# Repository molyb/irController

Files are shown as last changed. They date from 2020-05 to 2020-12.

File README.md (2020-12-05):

# irController

[PCB board](pcb) and [firmware](firmware)

# Mode Select
## Normal Mode
This mode can control consumer electronics.  

1. Just turn on or release the reset button.
2. Access the ip address that allocated by your router. 

## Network Config Mode
This mode configure Wi-Fi.
   
1. Press program button within one second of releasing the reset button,
    and hold down it for one second.
2. Connect to IR_CONTROLLER_AP.
3. You will be redirected to the configuration page automatically.
4. Input ssid and password, and click save button.

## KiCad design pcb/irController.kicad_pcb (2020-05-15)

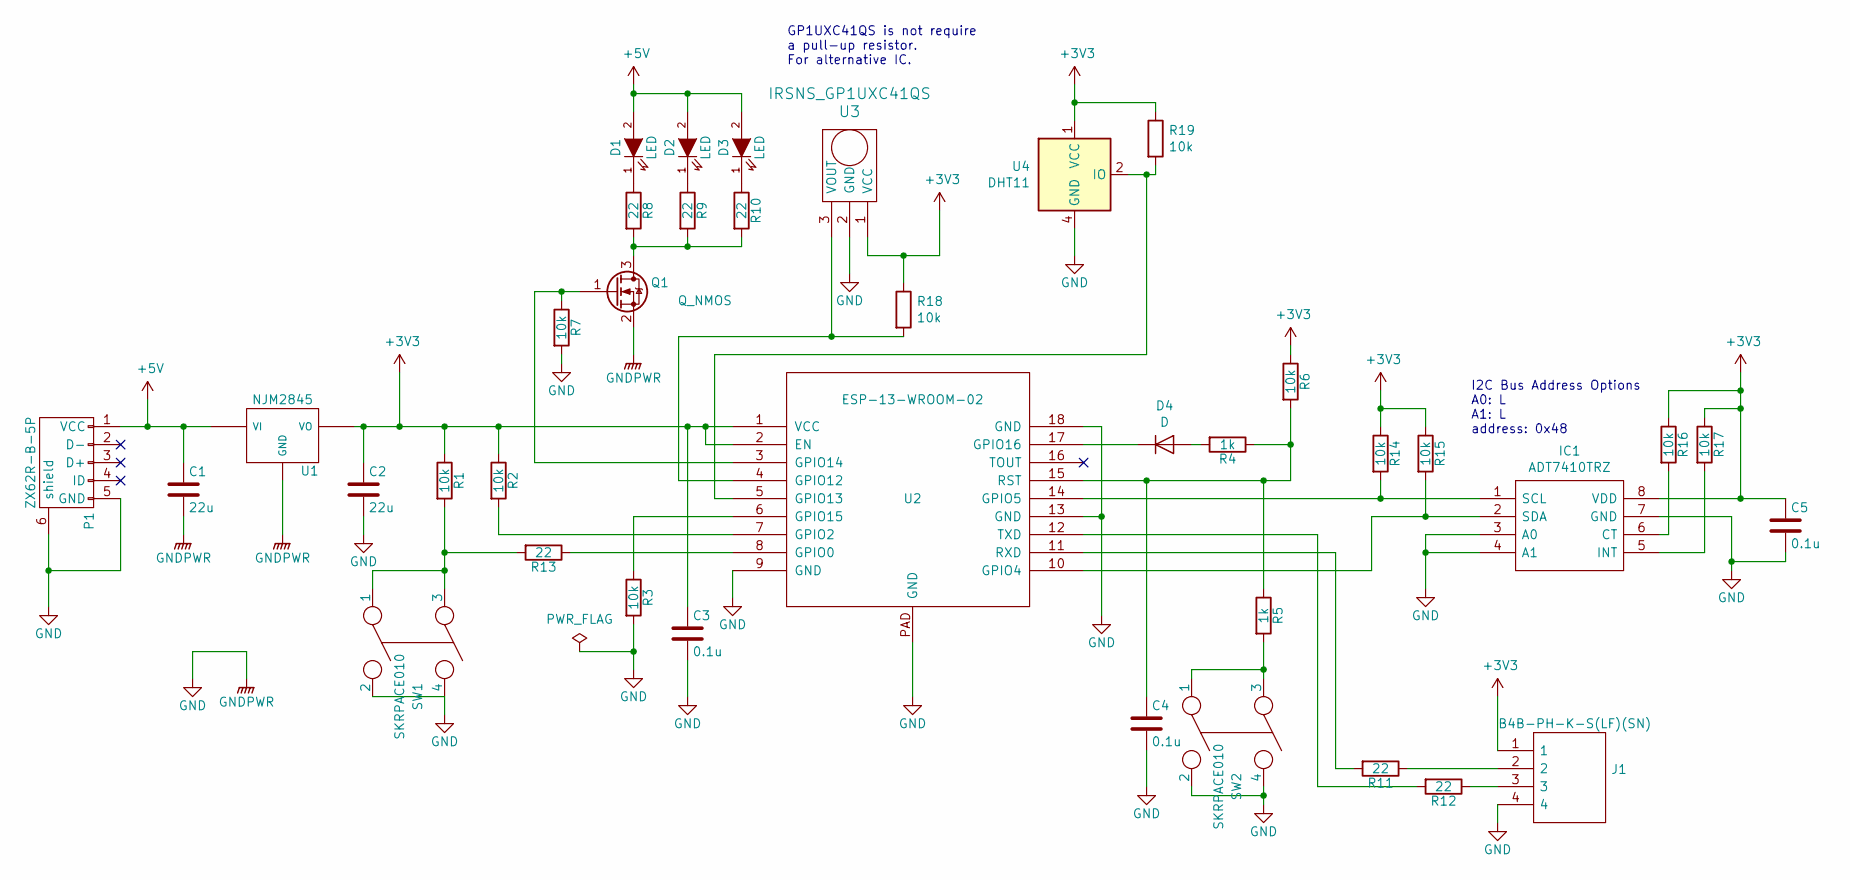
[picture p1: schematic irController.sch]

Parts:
C1, C2: 22u; C_1206_3216Metric
C3, C4, C5: 0.1u; C_0603_1608Metric
D1, D2, D3: LED; LED-5MM
D4: D; D_SOD-123F
IC1: ADT7410TRZ; SOIC127P600X175-8N; Manufacturer_Part_Number ADT7410TRZ; Mouser Part Number 584-ADT7410TRZ
J1: B4B-PH-K-S(LF)(SN); SHDR4W60P0X200_1X4_990X450X600P; Manufacturer_Part_Number B4B-PH-K-S(LF)(SN)
P1: ZX62R-B-5P; USB_Micro-B_Wuerth_629105150521
Q1: Q_NMOS; SOT-23
R1, R2, R3, R6, R7, R14, R15, R16, R17, R18, R19: 10k; R_0603_1608Metric
R4, R5: 1k; R_0603_1608Metric
R8, R9, R10, R11, R12, R13: 22; R_0603_1608Metric
SW1, SW2: SKRPACE010
U1: NJM2845; TO-252-3
U2: ESP-13-WROOM-02
U3: IRSNS_GP1UXC41QS; Socket_Strip_Straight_1x03
U4: DHT11; PinHeader_1x04_P2.54mm_Vertical

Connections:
+3V3: C2.1, C3.1, C5.1, IC1.8 (VDD), J1.1, R1.1, R2.1, R6.1, R14.1, R15.1, R16.1, R17.1, R18.1, R19.1, U1.VO, U2.1 (VCC), U2.2 (EN), U3.1 (VCC), U4.1 (VCC)
+5V: C1.1, D1.2 (A), D2.2 (A), D3.2 (A), P1.1 (VCC), U1.VI
GND: C1.2, C2.2, C3.2, C4.2, C5.2, IC1.3 (A0), IC1.4 (A1), IC1.7 (GND), J1.4, P1.5 (GND), P1.6 (shield), Q1.2 (S), R3.2, R7.2, SW1.2, SW1.4, SW2.2, SW2.4, U1.GND, U2.9 (GND), U2.13 (GND), U2.18 (GND), U2.PAD (GND), U3.2 (GND), U4.4 (GND)
unnamed: C4.1, R4.1, R5.1, R6.2, U2.15 (RST)
unnamed: D1.1 (K), R8.1
unnamed: D2.1 (K), R9.1
unnamed: D3.1 (K), R10.1
unnamed: D4.1 (K), U2.17 (GPIO16)
unnamed: D4.2 (A), R4.2
unnamed: IC1.1 (SCL), R14.2, U2.14 (GPIO5)
unnamed: IC1.2 (SDA), R15.2, U2.10 (GPIO4)
unnamed: IC1.5 (INT), R17.2
unnamed: IC1.6 (CT), R16.2
unnamed: J1.2, R11.1
unnamed: J1.3, R12.1
unnamed: Q1.1 (G), R7.1, U2.3 (GPIO14)
unnamed: Q1.3 (D), R8.2, R9.2, R10.2
unnamed: R1.2, R13.2, SW1.1, SW1.3
unnamed: R2.2, U2.7 (GPIO2)
unnamed: R3.1, U2.6 (GPIO15)
unnamed: R5.2, SW2.1, SW2.3
unnamed: R11.2, U2.11 (RXD)
unnamed: R12.2, U2.12 (TXD)
unnamed: R13.1, U2.8 (GPIO0)
unnamed: R18.2, U2.4 (GPIO12), U3.3 (VOUT)
unnamed: R19.2, U2.5 (GPIO13), U4.2 (IO)

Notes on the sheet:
I2C Bus Address Options A0: L A1: L address: 0x48
GP1UXC41QS is not require a pull-up resistor. For alternative IC.

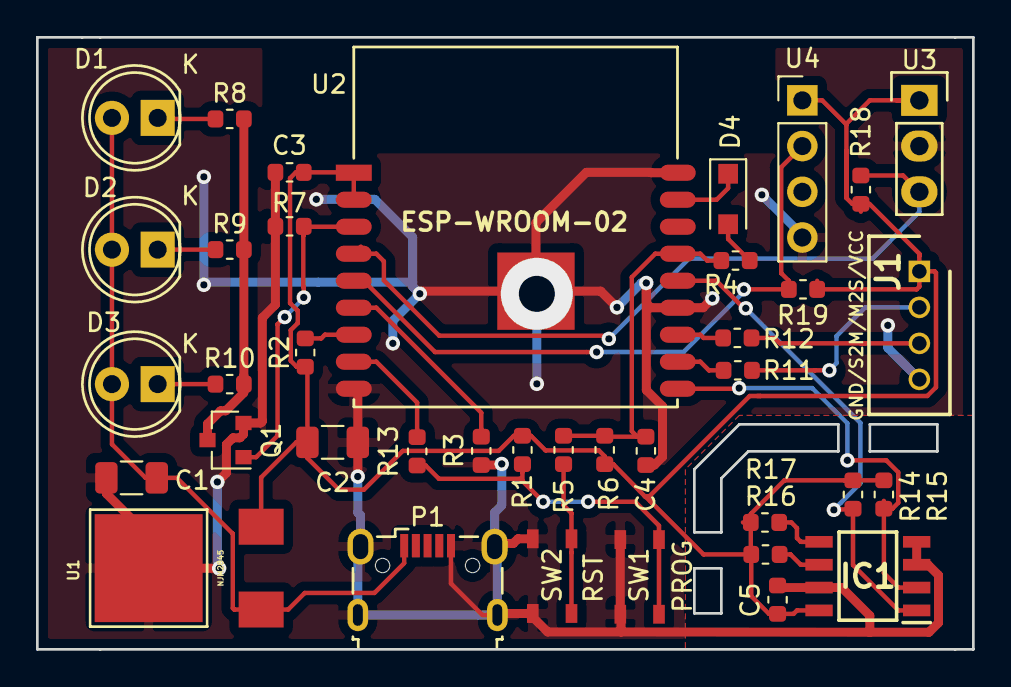
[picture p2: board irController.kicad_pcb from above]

Board: 2 copper layers, 52.0 x 34.0 mm, 38 parts (0 on the bottom side), 26 nets.

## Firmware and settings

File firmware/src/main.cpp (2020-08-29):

#include <Arduino.h>

#include "configMode.h"
#include "operationMode.h"

#define PROG_BUTTON 0


enum Mode {
    kOperationMode, kConfigMode
};

enum Mode mode = kOperationMode;

void setup() {
    pinMode(PROG_BUTTON, INPUT);
    // リセット解除後 1secの時点でボタンが押下されていればWifiの設定モードに入る
    delay(1000);
    if (digitalRead(PROG_BUTTON) == LOW) {
        mode = kConfigMode;
        setupConfigMode();
    } else {
        setupOperationMode();
    }
}

void loop() {
    if (mode == kConfigMode) {
        loopConfigMode();
    } else {
        loopOperationMode();
    }
}

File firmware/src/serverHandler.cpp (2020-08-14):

#include "serverHandler.h"
#include "MonitorTemperature.h"
// https://github.com/markszabo/IRremoteESP8266
#include <EEPROM.h>
#include <IRremoteESP8266.h>
#include <IRsend.h>
#include <IRrecv.h>
#include <ir_Hitachi.h>
#include <ArduinoJson.h>
#include "parameters.h"
#include "saveEvent.h"
#include "eventHandler.h"
#include "RtcEvent.h"

const unsigned int ir_out_pin = IR_OUT_PIN;
extern RtcEvent rtc;

#define JSON_CAPACITY 2048

void handleRoot(void) {
    File index = SPIFFS.open("/index.html", "r");
    if(!index) {
        Serial.println("Fail: load index.html");
        handleNotFound();
        return;
    }
    String html = index.readString();
    index.close();
    server.send(200, "text/html", html);
}


void handleNotFound(void) {
    // 内部ファイルシステムにファイルがあればリード
    String path = server.uri();
    if (SPIFFS.exists(path)) {
        File file = SPIFFS.open(path, "r");
        auto convertMimeType = [](String filename) -> String {
            if(filename.endsWith(".htm")) return "text/html";
            else if(filename.endsWith(".html")) return "text/html";
            else if(filename.endsWith(".css")) return "text/css";
            else if(filename.endsWith(".js")) return "application/javascript";
            else if(filename.endsWith(".png")) return "image/png";
            else if(filename.endsWith(".gif")) return "image/gif";
            else if(filename.endsWith(".jpg")) return "image/jpeg";
            else if(filename.endsWith(".ico")) return "image/x-icon";
            else if(filename.endsWith(".xml")) return "text/xml";
            return "text/plain";
        };
        String contentType = convertMimeType(path);
        server.streamFile(file, contentType);
        file.close();
        return;
    }

    String message = "File Not Found\n\n";
    message += "URI: ";
    message += server.uri();
    message += "\nMethod: ";
    message += (server.method() == HTTP_GET) ? "GET" : "POST";
    message += "\nArguments: ";
    message += server.args();
    message += "\n";
    for (uint8_t i = 0; i < server.args(); i++) {
        message += " " + server.argName(i) + ": " + server.arg(i) + "\n";
    }
    // HTTPステータスコード(404) 未検出(存在しないファイルにアクセス)
    server.send(404, "text/plain", message);
}


void handleTemperature(void) {
    monitor.update();
    float temperature = monitor.temperature();

    String message = "temperature: " + (String)temperature + " [deg]";
    server.send(200, "text/plain", message);
}


void handleLight(void) {
    File file = SPIFFS.open("/light.html", "r");
    if(!file) {
        Serial.println("Fail: load light.html");
        handleNotFound();
        return;
    }
    String html = file.readString();
    file.close();

    const uint64_t irPatternNecLightOn = 0x41B6659A;
    const uint64_t irPatternNecLightNight = 0x41b63dc2;
    const uint64_t irPatternNecLightOff = 0x41B67D82;
    const uint16_t irPatternBitsLightOn = 32;
    const uint16_t irPatternBitsLightNight = 32;
    const uint16_t irPatternBitsLightOff = 32;

    IRsend irsend(ir_out_pin);
    irsend.begin();
    enum State {
        unknown,
        on,
        night,
        off
    };
    __unused enum State state = unknown;
    //  LED の制御(server.method()でメソッドごとの処理を切り替えられるが今は同じにしておく)
    String val = server.arg("cmd");
    if (val == "on") {
        irsend.sendNEC(irPatternNecLightOn, irPatternBitsLightOn);
        state = on;
    } else if (val == "night") {
        irsend.sendNEC(irPatternNecLightNight, irPatternBitsLightNight);
        state = night;
    } else if (val == "off") {
        irsend.sendNEC(irPatternNecLightOff, irPatternBitsLightOff);
        state = off;
    } else {
        ;
    }

    __unused auto state2str = [](enum State state) {
        if (state == on) {
            return String("on");
        } else if (state == night) {
            return String("night");
        } else if (state == off) {
            return String("off");
        } else {
            ;
        }
        return String("unknown");
    };

    server.send(200, "text/html", html);
}


// swingは実装の手間と実用面を考慮してサポートしない
// IRremoteESP8266ライブラリのIRHitachiAc424メンバ関数setSwingVToggleコメントを参照
static void controlAc(IRHitachiAc424& ac, const String& power, const String& operation_mode, const String& temp,
        const String& fan, const String& swing) {
    ac.begin();

    if (power == "on") {
        ac.on();
    } else {
        ac.off();
    }
    if (operation_mode == "fan") {
        ac.setMode(kHitachiAc424Fan);
    } else if (operation_mode == "cool") {
        ac.setMode(kHitachiAc424Cool);
    } else if (operation_mode == "heat") {
        ac.setMode(kHitachiAc424Heat);
    } else if (operation_mode == "dry") {
        ac.setMode(kHitachiAc424Dry);
    } else {
        // IRHitachiAc424にはオートが無いのでひとまず送風にしておく
        ac.setMode(kHitachiAc424Fan);
    }
    // 数値に変換できない場合は0が返ってくるのでsetTempで保護処理される
    uint8_t num = strtol(temp.c_str(), NULL, 10);
    ac.setTemp(num);
    if (fan == "low") {
        ac.setFan(kHitachiAc424FanLow);
    } else if (fan == "medium") {
        ac.setFan(kHitachiAc424FanMedium);
    } else if (fan == "high") {
        ac.setFan(kHitachiAc424FanHigh);
    } else {
        // ライブラリにautoはあったが設定するとlowになる
        // 実際にも機能として無さそうなのでelseをlowにしてもいいかも
        ac.setFan(kHitachiAc424FanAuto);
    }
    ac.setButton(kHitachiAc424ButtonPowerMode);
    ac.send();
}


void handleHitachiAc(void) {
    static IRHitachiAc424 ac(ir_out_pin);
    // ctrlはエアコン制御では無くチップの制御用引数
    if (server.arg("ctrl") == "get_config") {
        server.send(200, "text/plain", ac.toString());
        return ;
    }

    String power = "off";
    String operation_mode = "fan";
    String temp = "22";
    String fan = "auto";
    String swing = "off";

    power = server.arg("power");
    operation_mode = server.arg("mode");
    temp = server.arg("temp");
    fan = server.arg("fan");
    // swing = server.arg("swing");

    // この判定処理が無いと設定のためにページひらいただけでエアコンが動作してしまう
    if (power == "on" || power == "off") {
        controlAc(ac, power, operation_mode, temp, fan, swing);
    }

    File file = SPIFFS.open("/hitachiAC.html", "r");
    if(!file) {
        Serial.println("Fail: load hitachiAC.html");
        handleNotFound();
        return;
    }
    String html = file.readString();
    file.close();

    // HTTPステータスコード(200) リクエストの成功
    server.send(200, "text/html", html);
}
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

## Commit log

2020-01-05 1st commit
    [irController-2020-01-05-11-28-17.sch, irController.csv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]
2020-01-05 バックアップファイル等削除し整理
    [irController-2020-01-05-11-28-17.sch, irController.sch]
2020-01-05 コネクタ変更
    [irController.sch]
2020-01-05 一旦完成
    [irController.kicad_pcb, irController.sch]
2020-03-28 発注時データ
    [irController-B_Cu.gbl, irController-B_Mask.gbs, irController-B_Paste.gbp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]
2020-03-28 フォルダ移動
    [irController-B_Cu.gbl, irController-B_Mask.gbs, irController-B_Paste.gbp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]
2020-03-29 gitignoreファイルを追加
2020-03-29 git管理不要なファイルを管理対象から削除
    [irController.csv, irController.dsn]
2020-03-29 ライブラリをサブモジュールとしてプロジェクト内に持たせた
2020-03-29 通信線の誤配線を修正
    [irController.sch]
2020-03-29 温度センサ搭載
    [irController.sch]
2020-03-29 ユーザ用ボタンをリセットボタンに変更
    [irController.sch]
2020-03-29 DRC対応
2020-03-29 LEDの電源電圧を選択できるようにした
    [irController.sch]
2020-03-29 パターン引いた
    [irController.kicad_pcb, irController.sch]
2020-03-31 LEDの駆動電流は5V固定にした
    [irController.kicad_pcb, irController.sch]
2020-03-31 発注データ
    [irController-B_Cu.gbl, irController-B_Mask.gbs, irController-B_Paste.gbp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]
2020-03-31 回路とファームを一元管理
2020-04-26 IC発熱を考慮して再配置
    [irController.kicad_pcb, irController.sch]
2020-05-30 プロジェクト設定
    依存ライブラリ設定等
    フォルダ名を変えたら自動でプロジェクト名も変わった
    (cherry picked from commit d78a6416cff3c20f1487afc298246e52a0f54fb1)
2020-05-30 アップロード処理を追加した
2020-05-30 所定の時刻に任意の処理をコールする機能を追加
    platformio.iniでプラットフォームバージョンを指定しているのは
    最新バージョンのconfigTime関数にバグがあるため
2020-05-30 実運用できる形に修正
2020-05-30 エアコン自動制御が入った際に任意の処理を挿入できるようにした
2020-06-14 WebUIから照明制御できるようにした
2020-06-14 WebUI上からエアコンを制御できるようにした
2020-06-14 トップページに各ページへのリンクを貼った
2020-06-14 callbackが正常に呼び出せない問題を修正
2020-06-27 Webサーバ用のデータをファイルシステム上のhtmlファイルに格納するようにした
2020-07-04 lightのハンドラもhtml化
2020-07-11 JSでHTMLパラメータを変更
2020-07-11 イベントをEEPROMに格納するクラスを作成
2020-07-11 EEPROMの値に基づきイベントを登録するようにした
2020-07-11 EEPROMに登録した情報をJSONで返すようにした
2020-07-11 チェックボックス表示
2020-07-24 イベント削除処理追加
2020-07-24 eepromからイベントerase時にチェックサムが不正値になってしまっていた問題を修正
2020-07-24 イベントがdeleteできない不具合を修正
2020-07-24 tickerの設定が更新できていなかった問題を修正
2020-07-24 冗長なシリアル出力を削除
2020-07-24 index.htmlからイベント設定ページに飛べるようにした
2020-07-25 webページ上でイベントが実行される曜日を設定および表示ができるようにした
    実際の発火処理はまだ
2020-07-25 POSTとGETで関数分割
2020-07-25 イベント実行週の設定が無い場合は登録しないように修正
2020-07-25 JSON用のメモリサイズ変更と最低限の保護処理追加
2020-07-26 曜日対応ひとまず書ききった
    未検証
2020-07-26 トップページリンク追加とリファクタリング
2020-07-26 ambientへのデータ登録処理有効化
2020-07-26 不要なコメント削除
2020-08-13 fix spelling of the header
    [serverHandler.cpp]
2020-12-05 correspond to heating start of AC

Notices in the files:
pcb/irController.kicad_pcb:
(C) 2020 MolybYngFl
